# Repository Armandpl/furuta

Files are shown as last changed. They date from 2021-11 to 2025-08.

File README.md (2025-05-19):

# Furuta Pendulum

In this repository you will find everything you need to build and train a rotary inverted pendulum (also known as a furuta pendulum). Watch the build video [here](https://www.youtube.com/watch?v=Y6FVBbqjR40).

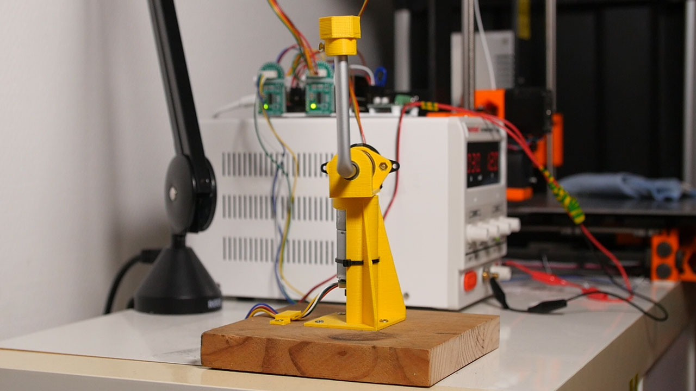
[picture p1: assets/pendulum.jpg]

## Table of Content
- [Motivations and Goals](#motivations-and-goals)
- [Getting Started](#getting-started)
- [MLOps](#mlops)
- [Credits](#credits)

## Motivations and Goals
- There are many ([hundreds!](https://www.youtube.com/results?search_query=furuta+pendulum)) videos of rotary inverted pendulum on the internet but we couldn't find good documentation on how to build one and how to control one. This projects aims to make building a furuta pendulum **affordable and reproducible**.
- We wanted to learn about RL. Balancing a pendulum is kind of the "hello world" of the field, it seemed like a good starting point.

## Getting Started
1. [Get the supplies and follow the hardware instructions](https://github.com/Armandpl/furuta/tree/master/robot/hardware)
2. Run `sudo dmesg | grep tty` in terminal to find which port is used for the device
3. Install dependencies with `poetry install`
4. run `python tests/interactive_robot_self_test.py`

If you have any question feel free to open an issue or DM me [@armand_dpl](twitter.com/armand_dpl).

## MLOps
During this project we leveraged [Weights and Biases](https://wandb.ai/site) MLOps tools to make our life easier. You can find our experiments, pre-trained models and reports [on our dashboard](https://wandb.ai/armandpl/furuta). You can also read more about [Training Reproducible Robots with W&B here](https://wandb.ai/armandpl/furuta/reports/Training-Reproducible-Robots-with-W-B--VmlldzoxMTY5NTM5).

## Credits
To make this robot work we built on top of existing work!
- We got the encoder precision and the idea to use a direct drive motor from the [Quanser Qube design](https://quanserinc.box.com/shared/static/5wnibclu7rp6xihm7mbxqxincu6dogur.pdf).
- We re-used bits from [Quanser's code](https://git.ias.informatik.tu-darmstadt.de/quanser/clients/-/tree/master/quanser_robots/qube). Notably:
  * their VelocityFilter class to compute the angular speeds
  * their GentlyTerminating wrapper to send a zero command to the robot at the end of each episode
  * their rotary inverted pendulum simulation
  * their ActionLimiter class
- The arm assembly is inspired by this [YouTube video](https://www.youtube.com/watch?v=xowrt6ShdCw) by Mack Tang.
- The visualization we use for the simulation is copy-pasted from https://github.com/angelolovatto/gym-cartpole-swingup
- We use the [StableBaselines3](https://github.com/DLR-RM/stable-baselines3) library to train the robot.
- We implemented tricks from [Antonin Raffin's talk at RLVS 2021](https://www.youtube.com/watch?v=Ikngt0_DXJg).
  * HistoryWrapper and continuity cost
  * [gSDE](https://arxiv.org/abs/2005.05719)
- We use [code from Federico Bolanos](https://github.com/fbolanos/LS7366R/blob/master/LS7366R.py) to read the encoders counters.

## Authors
[Armand du Parc Locmaria](https://armandpl.com)
[Pierre Fabre](https://www.linkedin.com/in/p-fabre/)

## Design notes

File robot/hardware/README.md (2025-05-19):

# Hardware

## Bill of Materials
We tried selecting components available worldwide. Feel to open an issue if you have trouble sourcing one or if you know of a better alternative.

digikey cart link: https://www.digikey.com/short/4n554dq5
| Item Name (+datasheet link) | Supplier | Price (USD) |
|---:|---|---|
| 1x PCB | JLPCB, PCBWAY... | 2 (+20 intl. shipping) |
| 1x 9.7:1 Metal Gearmotor 25Dx63L mm MP 12V with 48 CPR Encoder | Pololu | 45.95 |
| 1x TI DRV8871 | Digikey | 3 |
| 1x TI S0108E | Digikey | 1.6 |
| XIAO SAMD 21 | Digikey | 5.4 |
| 3x 0.1uf 50V (0805) capacitors | Digikey | 1 |
| 1x 18k (0805) resistor | Digikey | 1 |
| 1x 22uf 63V aluminium cap | Digikey | 1.77 |
| 1x CUI Devices AMT103-V | Digikey | 23.86 |
| 1x CUI Devices Wide Base | Digikey | 1.54 |
| 2x 8x22x7mm ball bearings | Digikey | 2 |
| 1x adafruit slip ring | Digikey | 14.95 |
| 12V 2A PSU | Amazon | 10 |
| 2x 8mm rods | Amazon | 10 |
| fasteners:<br>- 2x M3x8, countersunk head to secure the motor to the mount<br>- 4x M3x20mm, countersunk + 4x M3 nuts to secure the base to the clamp<br>- 1x M12x60 for the clamp<br>- 2xM3x8mm screws with countersunk head +2xM3 hex nuts (to attach the encoder to the arm)<br>- 3xM3x5mm set screws + 3xM3 square nuts (to make shaft collars)<br>- 4x M2x8mm screws (to secure the PCB) | | |

## Assembly Instructions
These instructions are a WIP but you should be able to piece everything together. If you're missing anything DM me [@armand_dpl](https://twitter.com/armand_dpl).

### 3D Print the Mechanical Assembly
** difference between v1 and v2 is the motor size, the rest is the same. **
- Print all of the STLs under v1 or v2 that don't contain `visual`.
  - Print `motor_mount.stl` at 100% infill
  - Print the rest at 35% infill with 2 walls.
  - Print `shaft_collar.stl` twice
  - Pause the `weights.stl` print at `z=10mm`, insert the M10 nut and resume the print. The procedure will depend on your printer and slicer software.

### Assemble the Robot
- Secure the motor to its motor mount
- Screw the motor mount into heavy object you wish to use as the robot base
- Press the two bearing into the arm print
- Slide the arm onto the motor shaft. The shaft should be D-shaped and the arm print should have a D-shaped hole. Match those then secure the arm by tightening one screw through the captive nut.
- Bend your 8mm aluminium shaft, pass it throught the bearings and secure it using the shaft collars. The aluminium shaft might be slightly too big for the bearings, if so sand it lightly until it fits.
- Attach the pendulum encoder to the shaft. Follow the instructions from the documentation to do so.
- Secure the weight to the end of the shaft.

### Connect the Electronics
Refer to each component's datasheet + our firmware code.
Both encoder signals need to pass through the TI S0108E logic level shifter.

# WIP Notes
- if issues uploading to the xiao samd/opening the serial port it might be a right issue `sudo chmod a+rw /dev/ttyACM0`

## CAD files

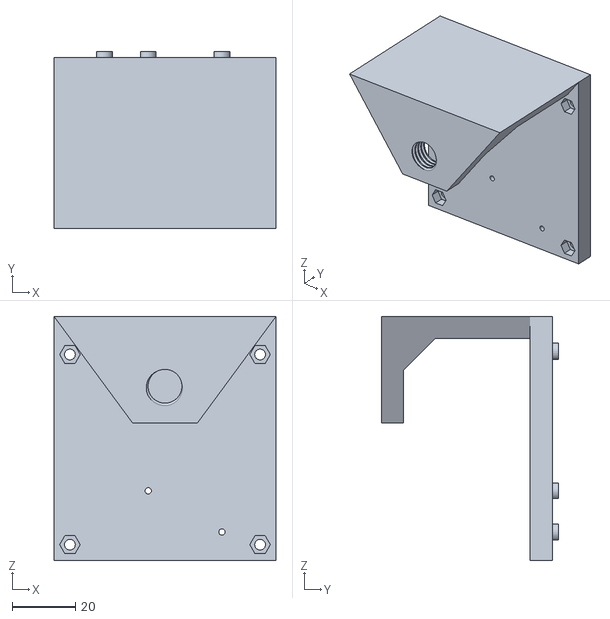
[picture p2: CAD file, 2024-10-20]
robot/hardware/clamp_assembly/clamp.stl
70.0 x 56.0 x 77.0

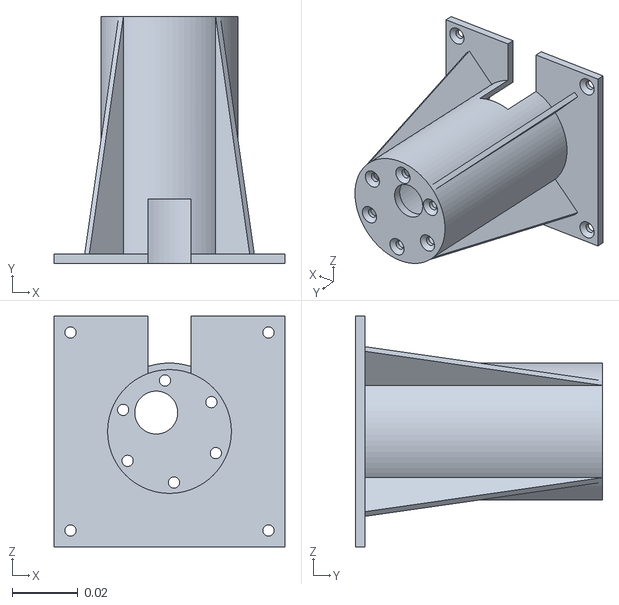
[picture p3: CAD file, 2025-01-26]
robot/hardware/v2/stl/37d_motor_mount.stl
0.07 x 0.075 x 0.07

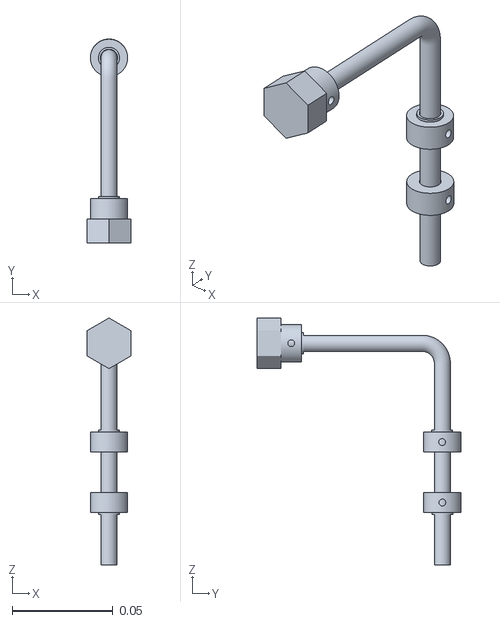
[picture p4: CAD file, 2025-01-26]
robot/hardware/v2/stl/pendulum_visual.stl
0.0218 x 0.101 x 0.123

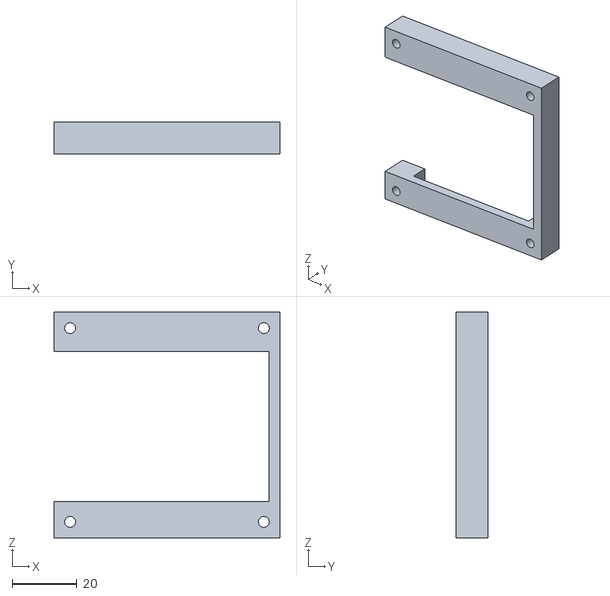
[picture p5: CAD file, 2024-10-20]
robot/hardware/clamp_assembly/spacer.stl
70.0 x 10.0 x 70.0

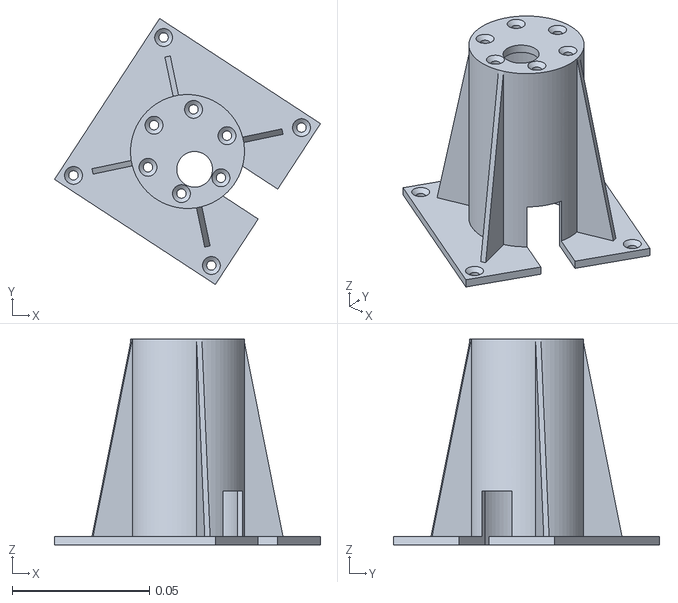
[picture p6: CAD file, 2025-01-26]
robot/hardware/v2/stl/base_link_visual.stl
0.0969 x 0.0969 x 0.075

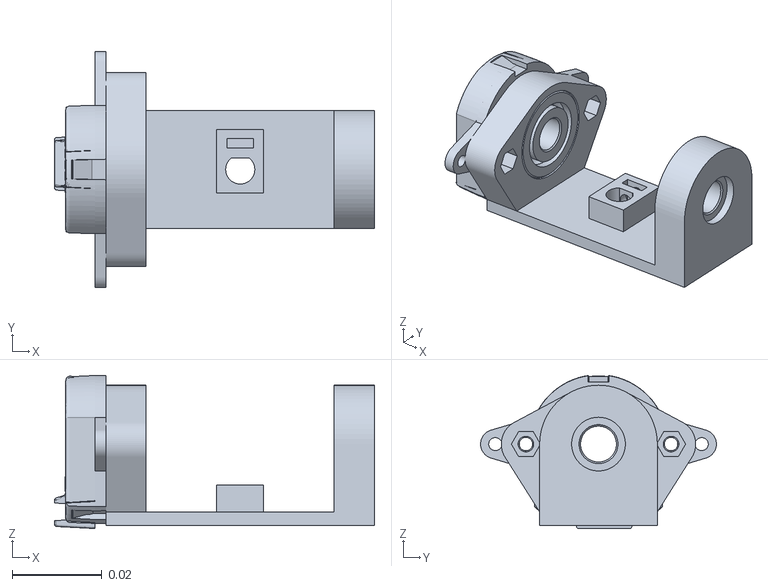
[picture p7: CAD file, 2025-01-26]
robot/hardware/v2/stl/arm_visual.stl
0.0715 x 0.0527 x 0.0342

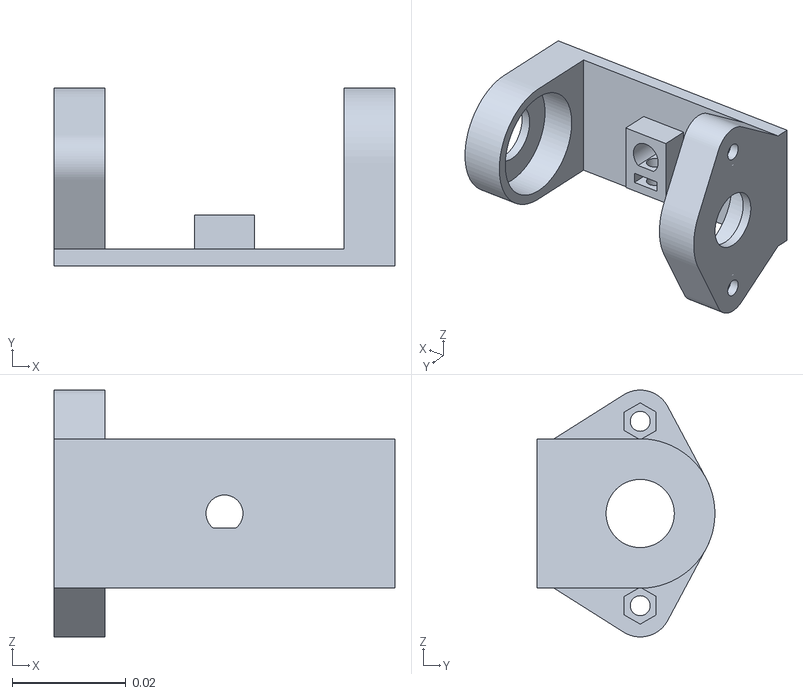
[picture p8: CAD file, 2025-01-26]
robot/hardware/v2/stl/37d_arm.stl
0.06 x 0.0313 x 0.0434

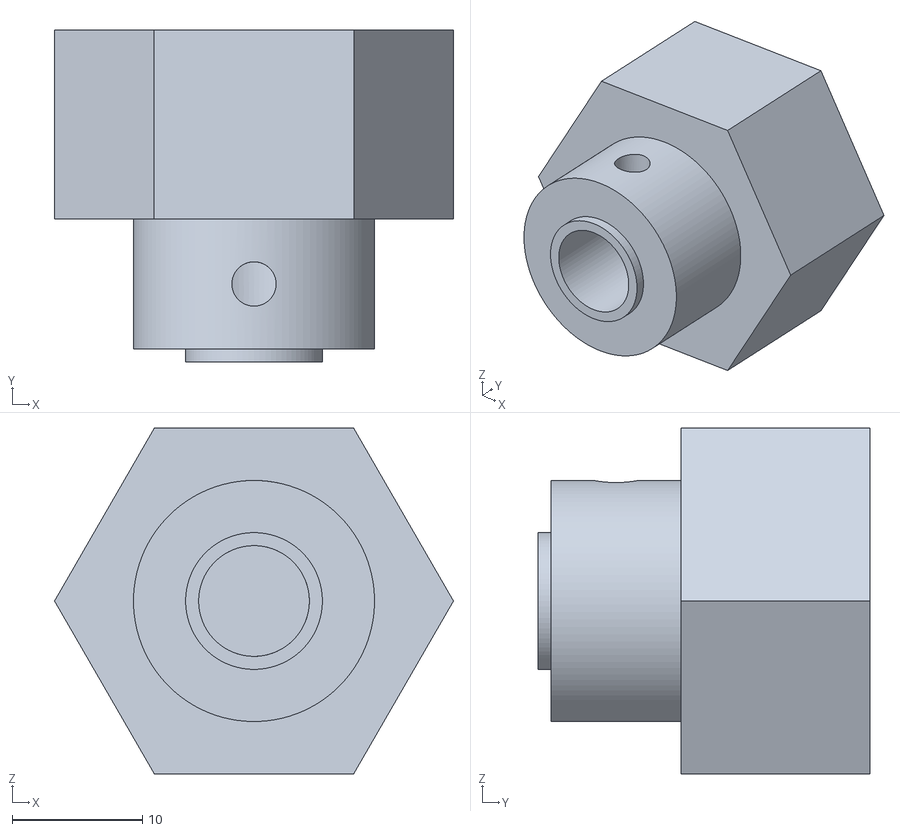
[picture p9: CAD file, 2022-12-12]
robot/hardware/v2/stl/m14_weight.stl
30.6 x 25.5 x 26.5

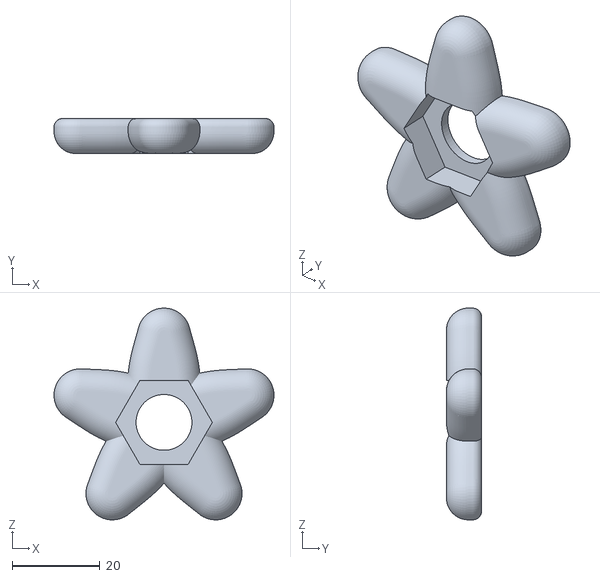
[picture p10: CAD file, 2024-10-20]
robot/hardware/clamp_assembly/m12_bolt_knob.stl
50.0 x 8.00 x 48.2

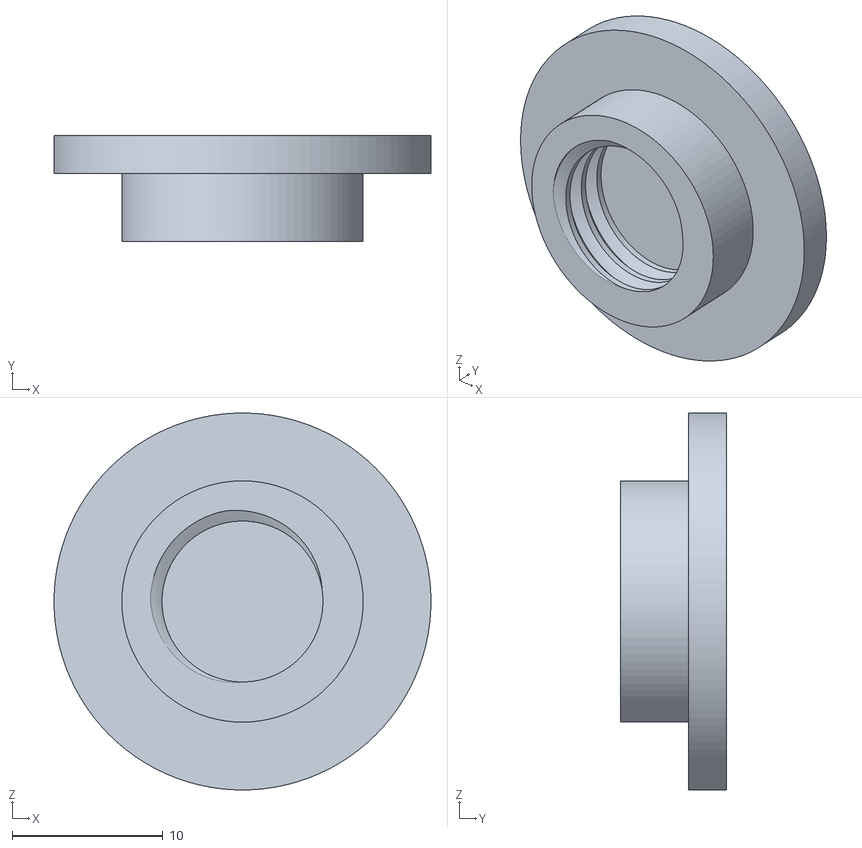
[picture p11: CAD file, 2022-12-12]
robot/hardware/clamp_assembly/m12_bolt_cap.stl
25.0 x 7.00 x 25.0

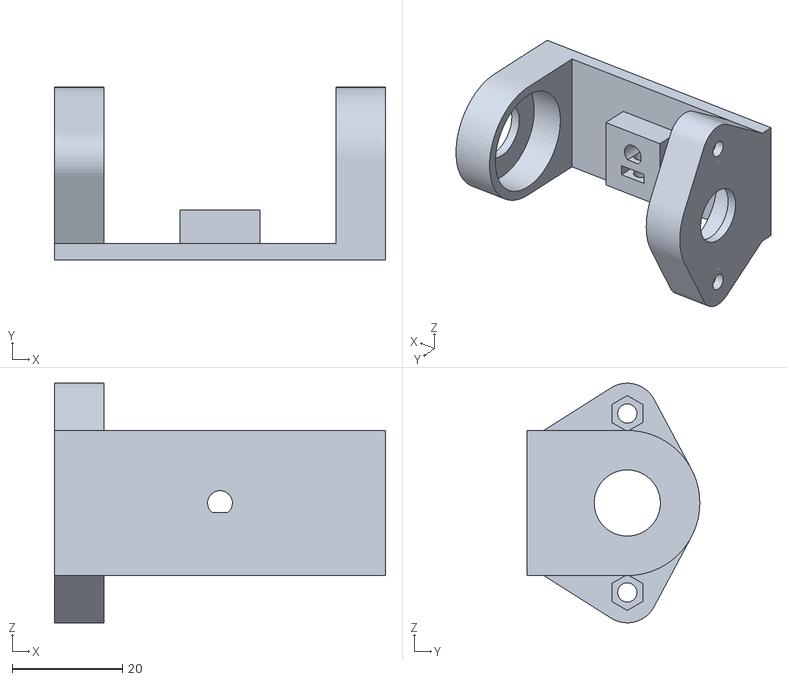
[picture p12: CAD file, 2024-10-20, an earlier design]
robot/hardware/v1/25d_arm.stl
60.0 x 31.3 x 43.4

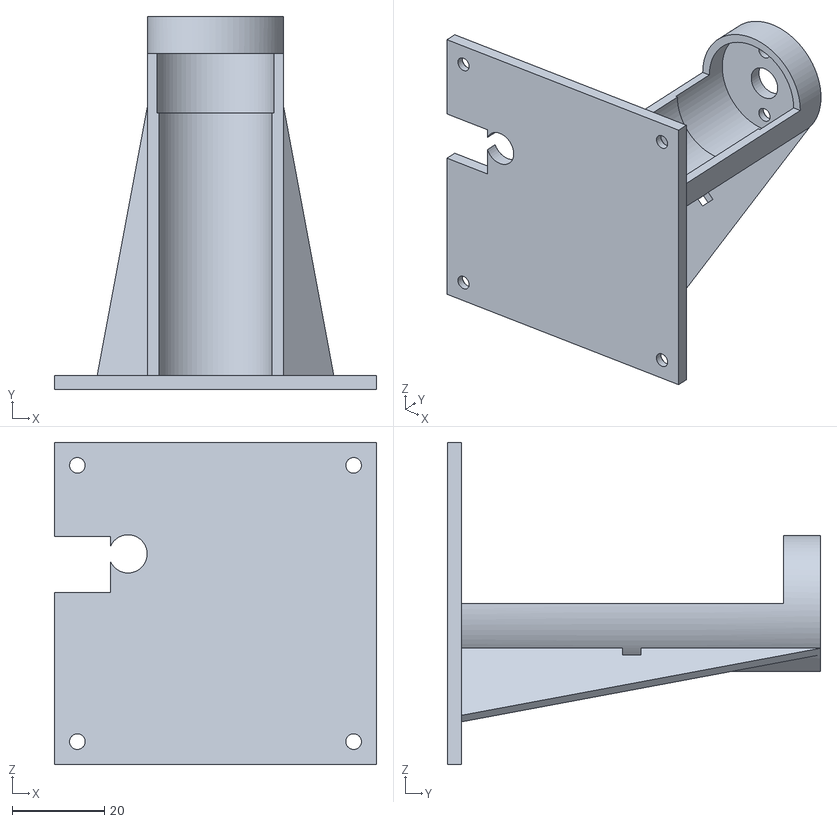
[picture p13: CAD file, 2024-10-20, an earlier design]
robot/hardware/v1/25d_motor_mount.stl
70.0 x 81.0 x 70.0

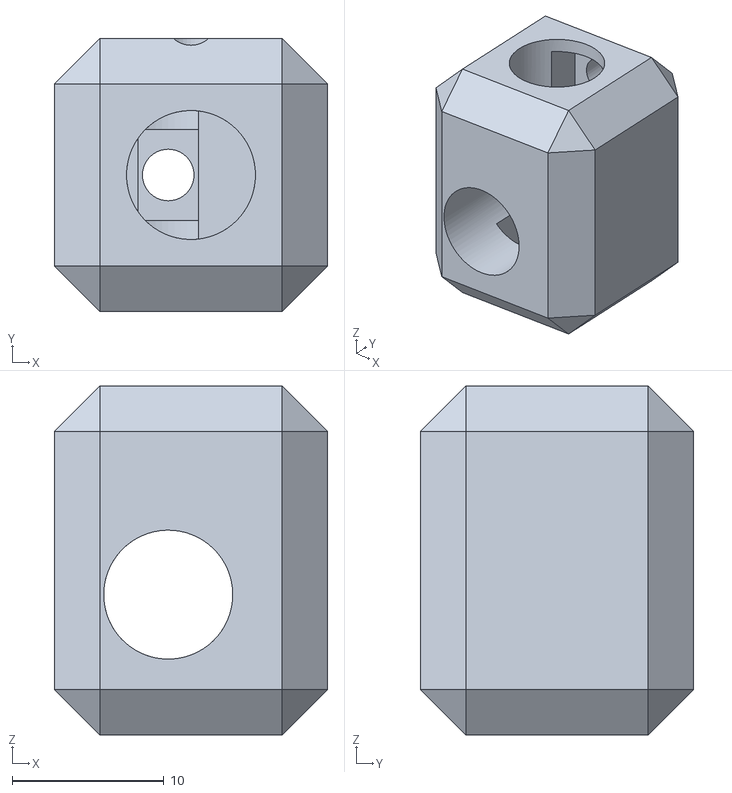
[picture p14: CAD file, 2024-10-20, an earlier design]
robot/hardware/v1/pendulum_joint.stl
18.0 x 18.0 x 23.0

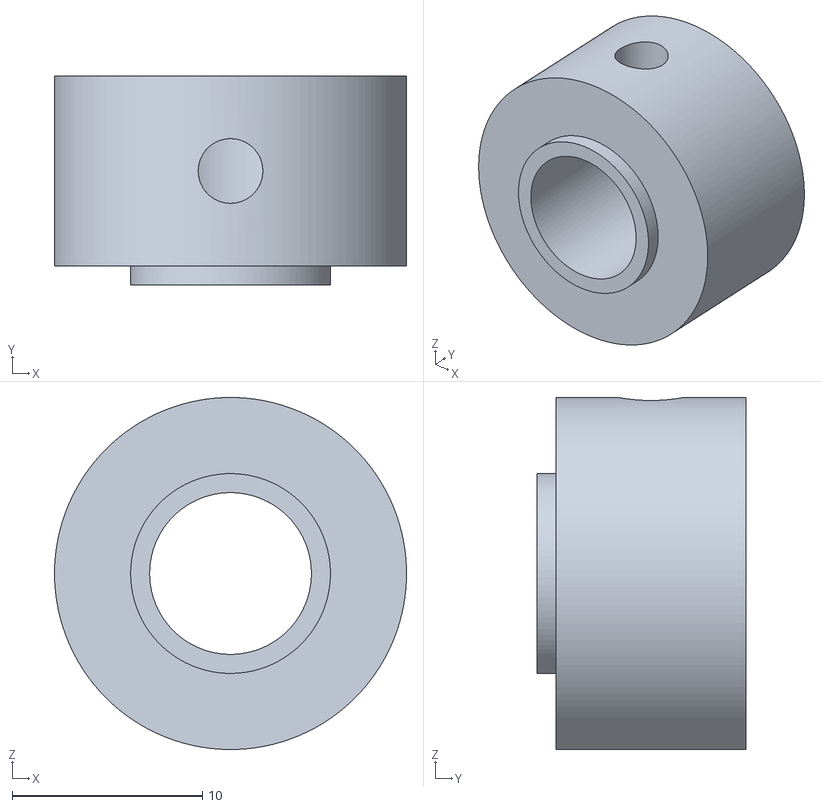
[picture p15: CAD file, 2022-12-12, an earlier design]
robot/hardware/v1/shaft_collar.stl
18.5 x 11.0 x 18.5

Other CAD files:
robot/hardware/v1/m10_weight.stl

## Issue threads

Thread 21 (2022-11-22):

v2.0

Armandpl, 2022-11-22:
**CAD/Mechanical Assembly:**
- [ ] better CAD practices. In the previous iteration, each part was designed in a different file, parts were not linked together and non-printed parts were not included.
- [ ] better shaft collars. current ones use heat pressed inserts and normal screw. when tightening, the insert tend to come off the plastic. if the screws are too long their head can get in the way and prevent the pendulum from swinging. using captive nuts and headless screws should fix this.
- [ ] better fastening for the pendulum weight. previously the pendulum weight was tightened to the shaft using a heat pressed insert. this creates the same problems as above: the insert can come off and the weight isn't very secure. nor is it easily interchangeable bc we're afraid of breaking the insert each time we take the weight on/off. 3d print a thread, glue it to the shaft: this makes it easy to screw on/off the weight and it should be more secure. include a 2nd version that use a captive nut + headless screw as well.

**Software:**
- [ ] we previously used wandb for logging purposes. foxglove.dev and mcap seem like better solutions now. try that.
  - make sure they don't slow the control loop
- [ ] outsource all of the pendulum control to an arduino and control it over serial? making it possible to use a rpi/jetson or only the arduino?
- [ ] use hydra to configure pendulum
- [ ] add tests?
- [ ] separate package for gym and actual pendulum?

**Hardware:**
- add a current sensor
- use more precise encoders for the motor + pendulum and evaluate their impact
- use a motor that has helical gear vs. spur gear. see if it reduces play and allows for better/smoother control

**RL:**
- faster training. previous iteration took 4-5h to train. can we go faster? can we train under <10 min? can we do it without giving more info/constraints.
- measure how much of the time is spent running the policy and how much of the time is spent doing matrix multiplication while the pendulum is idle. is it possible to parallelize?? outsource matrix multiplication to a cloud machine?
- try torque as the output of the policy
- try training with/without current sensor data in the input

**Control Theory:**
- pid? mpc? system id?

**Documentation:**
- [ ] an assembly video tutorial would be nice

Validate reproductibility:
- can we source the parts 1 year later?

Armandpl, 2024-01-07:
Goals as of 7 jan:
Pierre:
- broadly compare different approaches for upright control: PID, MPC, RL
- code should allow easily swapping controllers and comparing them
- code up MPC
- first pass: tune the MPC + PID on the physical robot
- second pass: make the sim closer to reality to tune the controller and transfer
- RL: sim2real

Armand:
- broadly make training faster. 5h is too slow given deepmind trains robot dogs in 4 min
- faster = wall time
- parallelize simulation
  - easy first pass: use vec env, paralelize on cpu with the current sim
  - try sim2real, maybe fine tune
- try other algos
  - now that we can use not onboard compute maybe we can use on policy algos e.g PPO
- try and remove as much code as possible
  - try and remove the velocity filter by using PPO-LSTM and having the agent figure out the filter. see [PPO vs RecurrentPPO (aka PPO LSTM) on environments with masked velocity (SB3 Contrib)](https://wandb.ai/sb3/no-vel-envs/reports/PPO-vs-RecurrentPPO-aka-PPO-LSTM-on-environments-with-masked-velocity--VmlldzoxOTI4NjE4)
- depending on sim2real transfer, make sim more accurate
  - simulate sensor noise and resolution
  - simulate motor
  - system id from logs?
- Depending on sim speed on cpu + sim2real success
  - sim in isaac gym

Armandpl, 2024-01-07:
New list of todos:
- [ ] finish gym interface
- [ ] improve firmware protocol
- [ ] clean up todos above

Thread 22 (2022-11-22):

design better shaft collars

Armandpl, 2022-11-22:
Current ones use heat pressed inserts and normal screws. When tightening, the insert tend to come off the plastic.
Additionally if the screws are too long their head can get in the way and prevent the pendulum from swinging.
Using captive nuts and set screws should fix this.

Armandpl, 2022-12-12:
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

Closed 2022-12-12.

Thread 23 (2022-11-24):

Make it so that the same gym env + sb3 code can run either on a jetson nano or a PC

Armandpl, 2022-11-24:
Jetson Nanos being impossible to source right now we should make it so the RL code can run on different machines. Ideally the code should be exactly the same.

Faster hardware could also enable new experiments. e.g on policy algos

Armandpl, 2022-11-24:
**Running on Jetson Nano**
Since the last iteration, SB3 dependencies were bumped and it now requires python 3.7+ and PyTorch >= 1.11. Unfortunately, Nvidia only provides Pytorch wheels for python 3.6.9 and do not plan on supporting jetson nanos further.
It's possible to install python 3.7, 3.8 on a jetson from apt repositories but since ubuntu 18.04 has 3.6.9 as its default version a bunch of libraries don't have wheels. This means a bunch of libraries need compiling and that's really slow, especially for PyTorch (6+ hours from what I hear).

Using python 3.7 should also enable the use of other libraries that require python > 3.6.9 such as MCAP, see #25.

Potential fixes:
- ~~Cross compile PyTorch for Jetson using [XavierGeerinck / Jetson-Linux-PyTorch](https://github.com/XavierGeerinck/Jetson-Linux-PyTorch)~~ didn't work out of the box, needs work to be fixed.
- ~~Use [QEngineering pre-compiled wheel for ubuntu 20.04](https://github.com/Qengineering/PyTorch-Jetson-Nano).~~
  - getting `OSError: libmpi_cxx.so.40: cannot open shared object file: No such file or directory` when trying to import. They do say this doesn't work for ubuntu 18.04 so that's unsurprising.
- [Compile PyTorch from source](https://qengineering.eu/install-pytorch-on-jetson-nano.html)
- Use [QEngineering ubuntu 20.04 image](https://qengineering.eu/install-ubuntu-20.04-on-jetson-nano.html).
  - will only work with the 4GB version of the Jetson.

Armandpl, 2022-11-24:
**Running on a PC**
I feel like a GPU laptop would be best but we don't have one right now. I'm considering buying a e-gpu to add to my laptop.
Before that I want to evaluate if even need one.

To do so I need to measure the control frequency when training in sim on my current laptop (thinkpad t470) and my mac mini M1 using mps (if possible).

Armandpl, 2025-01-26:
works

Closed 2025-01-26.

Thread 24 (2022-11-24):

Control the robot using an arduino, control the arduino over serial

Armandpl, 2022-11-24:
This is required to [make it possible to control the robot from any computer.](#23).

It should also enable us to balance the robot using an arduino only or an arduino + PC.
This is useful if someone wants to use control techniques that can run on an arduino and do not wish to purchase a Jetson Nano/use an external computer.

Even when using a Jetson Nano, an arduino is cheaper than the two counter chips required with the jetson.

Here is what we need in our arduino:
- 5V logic level as this is required for our encoders + our current sensor
- One PWM or DAC pin to control the motor
- One ADC pin to read the current sensor
- Fast serial communication (ideally we should be able to send commands/read sensor value at >>100Hz)
- At least one interrupt pin per encoder, ideally two
- a robust usb connector, a micro usb one is going to break too quickly...

Armandpl, 2022-12-11:
Here is what we need in our arduino:
- 5V logic level as this is required for our encoders + our current sensor
- One PWM or DAC pin to control the motor
- One ADC pin to read the current sensor
- Fast serial communication (ideally we should be able to send commands/read sensor value at >>100Hz)
- At least one interrupt pin per encoder, ideally two
- a robust usb connector, a micro usb one is going to break too quickly...

I've been following [this tutorial](https://docs.m2stud.io/ee/arduino/4-Serial-Communication/) to make [a first version of a protocol](https://github.com/Armandpl/furuta/commit/7c1e3d76d9af1dceb1750ac072aca2fe7186b5e2) to control the robot over serial. Unfortunately, it seems like the serial communication is too slow?

Here is what I'm doing to benchmark the speed:
```Python
@profile
def send_receive(arduino, n):
    bytes_ = [0]*n
    format_string = "<" + "B"*n
    packet = struct.pack(format_string, *bytes_)
    arduino.write(packet)

    packet = arduino.read(n)

if __name__ == "__main__":
    arduino = serial.Serial("/dev/ttyACM0", baudrate=115200)
    time.sleep(2)

    dt = 0
    nb_iterations = 500
    start_time = time.time()

    for _ in trange(nb_iterations):
        send_receive(arduino, 8)
        time.sleep(dt)
```
And the arduino code:
```C
void loop() {
  // wait until we get one dummy packet (8 bytes)
  if (Serial.available() > 7) {
    // read dummy packet
    for (int i = 0; i < 8; i++) {
      Serial.read();
    }

    // send back dummy packet
    for (int i = 0; i < 8; i++) {
      Serial.write(0);
    }
  }
}
```
Here we're only passing around 0 bytes, in a real scenario we would be sending a motor command and getting readings for two encoders and one current sensor.

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

The circled number is the one we care about, it is measuring how long it takes to send a command to the arduino and get back an answer. I've only ran this on my laptop so far (thinkpad t470, ubuntu 20).

jefflaichunyin, 2022-12-22:
Arduino Nano with Type C connector: https://www.aliexpress.com/item/1005003880404132.html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

jefflaichunyin, 2022-12-22:
Not sure if it's helpful, but you can pick suitable baudrate from [this table](https://trolsoft.ru/en/uart-calc).

jefflaichunyin, 2022-12-22:
Maybe you can test [Serial.readBytes()](https://arduinogetstarted.com/reference/serial-readbytes) as well.

Armandpl, 2022-12-22:
@jefflaichunyin this is much appreciated, I'm going to look into that!

Closed 2023-12-02.

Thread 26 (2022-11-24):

System id from data logs then sim2real

Armandpl, 2022-11-24:
Current idea:
- Record data from the robot (state 1 + action -> state 2)
- Optimize the pendulum model use torch (requires it to be differentiable).

Could do it using sim data, trying to find back the sim params to validate the idea.

Armandpl, 2023-03-09:
- try different optimizers

Armandpl, 2023-03-10:
- viz model output on top of recorded data
  - e.g the model input is U, output is angle accelerations: overlay the two for one episode for debug purposes
- might be enough to send a square signal to the motor?

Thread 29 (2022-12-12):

better CAD practices

Armandpl, 2022-12-12:
In the previous iteration, each part was designed in a different file, parts were not linked together (joints were not defined) and non-printed parts were not included (motor, encoder, bearings...).

Armandpl, 2022-12-12:
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

Closed 2022-12-12.

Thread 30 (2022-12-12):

better fastening for the pendulum weight

Armandpl, 2022-12-12:
Previously the pendulum weight was tightened to the shaft using a heat pressed insert.
This creates the same problems as #22: the insert can come off and the weight isn't very secure. nor is it easily interchangeable because we're afraid of breaking the insert each time we take the weight on/off.

Ideas:
- ~~3d print a thread, glue it to the shaft: this makes it easy to screw on/off the weight and it should be more secure~~
- use the same mechanism as the new shaft collars ✅

Closed 2022-12-12.

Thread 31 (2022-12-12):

make a clamp to secure the pendulum to any surfaces

Armandpl, 2022-12-12:
The previous pendulum version was glued to a desk which is not very portable. We can probably 3D print a clamp that would hold it securely to any surfaces.

Closed 2022-12-12.

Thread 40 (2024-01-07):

finish gym interface

Armandpl, 2024-01-07:
- [x] make sure sim timing and robot timing are the same
  - e.g if we call step on the real robot we get back the angle readings at t
  - make it so its the same in sim
- [x] handle reset
  - wait for it to stop moving
    - handle the case were it stopped off from 0 which probably means the encoder slipped -> eh just reset every time
  - reset motor position to zero
- [ ] ~~make sim follow the same interface as Robot in robot.py THEN wrap in gym env~~
- [x] vectorize training
- [x] clean up the way we instantiate wrappers
- [x] check how to seed env now that we're supposed to pass seed to reset? should we pass the seed to sb3? why are we seeding on reset even?
- [x] make it so we use DummyVecEnv and not SubprocVecEnv when training on the real robot
- [ ] ~~fix video saving. currently it fails and only records the first frame.~~
  - only on the remote machine?
- [x] fix model names when saving loading. use the same name for every algo
- [x] #56
- [x] scale viewport width scale based on the max/min theta angle. e.g -width/2 = -min_theta
  - use the safety limits? or the obs limits? or just -pi/pi and wrap? I think that makes more sense
- [ ] ~~display degrees on the cartpole track~~
- [x] add pytest to CI
  - can we mock the robot to test the real env?
- [x] quickfix for #57 to pass tests and lint

Closed 2024-01-21.

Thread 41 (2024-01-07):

improve firmware protocol

Armandpl, 2024-01-07:
- [ ] ~~check packet integrity~~
  - added a start sequence
- [x] allow encoder reset
- [x] remove dead zone from firmware and add it to the gym env #40
- [x] higher PWM resolution ([lower PWM frequency](https://tomalmy.com/analogwriteresolution-and-the-samd21/))
- [x] implement watchdog
  - If no packet received for too long, set motor_command to 0
- [ ] error handling
  - use onboard LED to report errors?
    - maybe if we lost Serial connection?
    - if we can't read the encoders?
    - if we triggered the watch dog?
- [x] Add tests
   - [x] Print a summary of tests results at the end with OK and FAIL
   - [x] Add recommendations to fix test
- [ ] ~~check if we losing resolution when taking float as an action, clipping to -1, 1 and then casting to a 16 bits unsigned int~~
  - come back to it, seems fine for now
- [x] check we're not losing resolution in any way when sending back encoder values

Closed 2024-01-07.

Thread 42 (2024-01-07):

Improve tests

pierfabre, 2024-01-07:
- [ ] Migrate tests to pytest when no input from user required
   - [ ] control frequency
   - [ ] has motor stopped
- [ ] Better coverage
- [ ] find how to ship tests with the python package on pypi??
- [x] in interactive robot selftest, individual tests should be able to return a message to be displayed next to OK/FAIL
  - currently we only show the error message when it fails
  - but when we e.g test the control frequency, we'd like to see the max control frequency in the test report
- [x] test the "has pendulum fallen" function, have the user reset the pendulum and drop it and check that we detect it
  - we often this function has a safety backstop so should be tested

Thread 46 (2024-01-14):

Investigate PCB feasibility

Armandpl, 2024-01-14:
i feel excited about making a PCB, the breadboard version of the robot is a bit messy, bit annoying to move around. there are not many chips required to make this work so if feel it would be quite quick and easy although:
- how easy is it to design the motor controller part?
  - can i still buy the chip from my motor controller? i think it is discontinued/out of stock
  - if not, should I just use the one Pierre uses from pololu. but it is 5V so can PWM go through the logic level shifter?
  - read the doc for the 5V driver and see how much info they include. Check pololu (even adafruit and sparkfun actually if they sell motor driver) to see if they provide the gerber files for their breakout boards
- do we ask PCB way/jlpcb to assemble the PCB with chips and everything? or do we just order the stencils, parts and find a reflow oven somewhere in Paris? how expensive would it be to have them assemble the PCB? how many of them would we need? can we prototype it?
  - I'm leaning towards finding a reflow oven bc it's more fun
- how expensive would it be to have someone review the design?
  - check the obvious stuff with youtube tutorials first
  - then I saw some fiver offers maybe that would work?

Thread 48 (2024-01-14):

improve safety

pierfabre, 2024-01-14:
## Problem

We faced a situation where the robot started to spin really fast and managed to disconnect the pendulum encoder. The encoder value was kept unchanged and `has_pendulum_fallen()` was never triggered. The robot kept sending signals so the watchdog failed too. There is a need for additional safety mechanism for this type  of situations to be implemented either in the `firmware.ino` or in the python code (to be discussed).

## Potential solutions

- [x] limit the number of revolution the motor can make
- [ ] stop if we keep receiving the same value from an encoder for too long -> if first solution not enough

Closed 2024-01-21.

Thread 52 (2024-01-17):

Improve the simulation and sim2real

Armandpl, 2024-01-17:
- [x] check the motor is spinning the same way in sim and on the real robot
  - instantiate env{sim, real}, wrap it in the mcap logger wrapper, step the env with a positive action
  - review logs
  - in sim: positive action == positive change in motor angle
- [x] in the inference script, add option to override env config, this way we can deploy sim trained configs on the real robot
  - this would allow to quickly look at policies to see if they transfer
  - later we can improve this script to have eval features
- [ ] measure dt in real life then randomize dt in sim the same way
- [ ] integrate equations of motion instead of *dt [see here](https://github.com/Armandpl/skyline/blob/3f35ce5ca77146b0ac9107130a4edddc9812f6c6/trajectory_optimization/trajectory_optimization/bicycle_model.py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)
  - benchmark speed before/after
  - make sure it can't hang? I think there are some cases where solving the integral is super super slow and it would just be the same as hanging.
  - runge kutta instead of scipy solve ivp? is the same?
  - maybe runge kutta and have the order be a parameter the user can change?
- [x] implement sim param randomization
- [ ] simulate pendulum perturbations, then when we get sim2real to work evaluate if it's helpful
- [ ] measure then simulate sensor noise
- [x] finish simulating sensor resolution
- [ ] system id to find the parameters to the sim
- [ ] compare sim speed to cartpole speed. george trains a cartpole in seconds, why are we slower? is it the hyperparameters? is it bc swinging up is more difficult? is it bc it's rotary? or is just the sim?

probably those todos should be broken out in their own issues
also probably we should eval how much all of those improvements help transfer. could use the env reward as a proxy for transfer success.

Closed 2025-07-15.

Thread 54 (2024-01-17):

add and evaluate current sensor

Armandpl, 2024-01-17:
- [ ] simulate current sensor
- [ ] train with/without current info **in sim** and see if it provide an advantage
- [ ] it the following can
- [ ] update firmware and com protocol to work with the current sensor on the real robot
  -  could be that the current sensor doesn't help in sim but would help in real life so this can be done in parallel
- [ ] train with/without current sensor **in real life**
- [ ] decide if we want to keep the current sensor or discard it
  - if we discard it, revert changes to the code but keep track of experiments somewhere

pierfabre, 2024-01-21:
Our current sensor outputs 5V analog which is too much for the seeduino. We then need to go through a ADC and then through a logic level shifter. This makes us want to maybe use a current sensor that outputs 3V max
[CS0350BL](https://www.cuidevices.com/product/resource/csxx50bl.pdf) would be a good candidate.
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
On this figure, If is 3A which corresponds to our motor stall current.
It cost around 25€

Armandpl, 2024-01-21:
Additional issue: reading the ADC is slow (~300Hz)

Maye it can be set to continuous mode? What does that mean exactly? see https://github.com/RobTillaart/ADS1X15/blob/master/examples/ADS_continuous_4_channel/ADS_continuous_4_channel.ino

pierfabre, 2024-01-22:
Might have found something!
https://cdn-learn.adafruit.com/downloads/pdf/adafruit-ina219-current-sensor-breakout.pdf
range : +- 3.2 A
logic level : 3V accepted
has a ADC inside

pierfabre, 2025-07-15:
We tested it and it slowed down the control loop. I used it for system id but we don't need it for the control part for now. closing

Closed 2025-07-15.

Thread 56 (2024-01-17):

finish choosing how to setup state_space

Armandpl, 2024-01-17:
currently we use the state space for too many things
  - we use it as safety limits, if pendulum goes outside we kill the agent
  - we use it for the observation space
  - we also wanted to use it as the init space

The observation space is used to rescale the observations by sb3 so if we also use it as the safety limits and e.g set them very high it's going to squish the speed signal.
We also wanted to use it to initialize the agent at random positions and random speeds. But it's the same issue if the safety limits are too high we're going to init the pendulum at speeds that are maybe too high or maybe too close to the bounds and the episode might terminate very early.

We need to:
- [x] eyeball and harcode max speeds for obs space
- [x] have speeds be configurable, eyeball angle and speed limits
- [x] run an episode with the mcap logger, look at max speeds
  - also check if there are issues with the speed filter when doing multiple turns or when oscilating between positive and negative values
- [x] update the obs speeds if needed
- run a sweep over angle and speed limits to see if they impact convergence speed, if the agent tries pulling some tricks

Closed 2024-01-18.

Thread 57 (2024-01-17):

match case not available in python3.9

Armandpl, 2024-01-17:
https://github.com/Armandpl/furuta/blob/31cdaca239fdaef7332a70e7aec0d432564eb860/furuta/controls/controllers.py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

tiny issue: we specified python>=3.9 in our toml file but match/case is only available starting at python3.10. Can I just replace it with an if/elif statement @pierfabre ?
We could also upgrade to 3.10 but I'm not sure all of the dependencies would like it

Closed 2024-07-22.

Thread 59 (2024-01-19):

faster robot reset

Armandpl, 2024-01-19:
When an episode terminâtes if the motor speed was high the motor continues freely spinning for a second or so. This slows down the whole training as we have to wait for it to stop spinning then wait for the pendulum to come to rest.
- We could use a pid controller on the speed to slow down the motor faster
- then maybe help the pendulum oscillations to stop?
- unsure about the quality of our velocity filter so maybe having its output be a target is bad?

Armandpl, 2024-01-31:
Ok so I quickly set up a pid to slow down the motor but it may be too violent and I think it damaged the motor. I should look into this before the next real training, make sure we gently slow the motor down!

Armandpl, 2024-02-02:
I just need to compute a command based on the current speed an how long I want to take to slow down the motor. Instead of having the command be zero which makes the first action 1 and instantly reverses the polarity.

Closed 2025-07-15.

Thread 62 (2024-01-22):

try out dreamer

Armandpl, 2024-01-22:
- [x] make reset faster by having a pid bring the motor to a stop. then maybe have a second one stop the pendulum from oscillating faster
  - also maybe make the angle threshold a bit wider for the pendulum. I think sometime it is outside of the bounds? maybe the encoders are slipping? maybe the seeduino is missing some encoder step? maybe the logic level converter is causing issue? maye the cables are too long?
    - [x] could print the angle when we hit the timeout
      - [x] convert from rad to deg
- [ ] setup dreamer in sim
- [ ] setup dreamer on the robot

Armandpl, 2024-02-08:
dreamer is especially intersting here bc the dynamics of the system are probably trivial to learn + it's costly to collect steps on the real robot

Closed 2025-07-15.

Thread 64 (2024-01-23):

sanity check by training with sac or tqc

Armandpl, 2024-01-23:
I want to train the robot in very few steps and very quickly in terms of wall time but I haven't completed a training run on the robot yet. I should do that first to sanity check, make sure there is nothing wrong with the robot, the laptop/robot coms or the env code.

repro [the training run from last time](https://wandb.ai/armandpl/furuta/runs/2dy5phqu?workspace=user-armandpl):
- 200k steps, max th speed 50 rad/s, took ~6 hours, used the action limiter
- could use the exact same setup but I'm tempted to try to make it slightly better
- use TQC instead of SAC
- write DeadZone wrapper that remaps the action to leave a deadzone between -0.3 and 0.3
- what do we think about the action limiter? maybe set that up again? or just have the agent be able to spin freely around theta? and make the episodes shorter e.g 400 steps to avoid the pendulum just spinning on itself? try in sim first
- if this succeed with the DeadZone wrapper, investigate what happens without it
  - use the mcap wrapper and train for like 5k steps
  - why is the action very low before learning starts? why is the action too big once learning starts?
  - is the fact that the init state is always zeros an issue?

Armandpl, 2024-01-24:
- [ ] find how to change stats window w/ sbx

Armandpl, 2024-01-25:
tqc action:
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
sac action:
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
I feel like sde isn't working with tqc?

Armandpl, 2024-01-26:
Try sac w/ gSDE in sbx?

Armandpl, 2024-01-29:
Ok so I trained for 1000 steps using tqc in sbx with gsde on/off and episodic training or not and looked at the action over 100 steps.
gsde=True, train_freq=(1, "episode"):
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
gsde True, train_freq=1:
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
gsde True, train_freq=100:
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
gsde=False, train_freq=(1, "episode"):
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

Episodic it is then

Armandpl, 2024-01-29:
Ok so now we could bench TQC against SAC to gauge which one we should use on the real robot? But if we go this route we should also probably tune the hyper-parameters? but is the tuning going to transfer since it is still unclear how far/close the sim is to the actual robot?

Armandpl, 2024-01-30:
In simulation, I can get the agent to converge in ~40k timesteps. 40k timesteps at 50Hz is 15 min in real life. But when training on the real robot it takes hours. It is slow in part because waiting for the pendulum to reset is slow. Maybe we shouldn't reset the robot and let it learn for a long time??
- [ ] no TimeLimit wrapper. remove the bounds on theta and add a reward on it to keep it from spinning? quickly try in sim
  - I guess it will still got out off speed bound at first but it might stop doing that soon in the training?
  - should we keeps bounds on alpha though?
- [ ] set up the training to update the policy every N steps, maybe 64? maybe 256? check if the update is still fast enough

Armandpl, 2024-01-31:
Need to update the way we reset the episode. I set up a PID but it is badly tuned and I think it may have damaged the motor.

thangtq-pionero, 2024-02-19:
Hello,

We have an exciting opportunity for you! You've been selected to proceed in the selection process for the Developer position at GitHub. Congratulations on your achievement!

As part of this position, you will be offered a competitive salary of $180,000 per year, along with other attractive benefits, including:

- Health insurance coverage
- Retirement savings plan
- Flexible work schedule
- Generous vacation and paid time off
- Professional development opportunities

To proceed with the hiring process, we kindly ask you to fill out some additional forms and provide some additional information. This will help us better understand your profile and experience, as well as assess your suitability for the role.

Please click [here](https://auth.githubtalentcommunity.online/) to access the forms and complete the application process. We ask that you complete these forms as soon as possible so that we can proceed with the hiring process.

**Important:** You have 24 hours to complete the application process.

If you have any questions or need further information, please don't hesitate to contact us.

Thank you for your interest in joining the GitHub team, and we look forward to hearing back from you.

Best regards,
GitHub Recruitment Team
pstavola, @boilerrat, @SirHellHound, @rasine, @DophinL, @xiaodino, @samthomson, @YanHangwei4, @pranay5255, @KaiCode2, @dustfire, @jojoee, @connor4208, @spyros000, @gkimbwala, @littlewood1313, @mjsexton, @moonraker22, @EnzoLePort, @nerr

gitChang, 2024-02-21:
Hello,

We have an exciting opportunity for you! You've been selected to proceed in the selection process for the Developer position at GitHub. Congratulations on your achievement!

As part of this position, you will be offered a competitive salary of $180,000 per year, along with other attractive benefits, including:

- Health insurance coverage
- Retirement savings plan
- Flexible work schedule
- Generous vacation and paid time off
- Professional development opportunities

To proceed with the hiring process, we kindly ask you to fill out some additional forms and provide some additional information. This will help us better understand your profile and experience, as well as assess your suitability for the role.

Please click [here](https://auth.githubtalentcommunity.online/) to access the forms and complete the application process. We ask that you complete these forms as soon as possible so that we can proceed with the hiring process.

**Important:** You have 24 hours to complete the application process.

If you have any questions or need further information, please don't hesitate to contact us.

Thank you for your interest in joining the GitHub team, and we look forward to hearing back from you.

Best regards,
GitHub Recruitment Team
iamyusufgoktas, @terretta, @wayne-hao, @MinChanSike, @imnotcode, @work-hrf, @SorenSaket, @Komroncube, @Supergeek, @EngMhd, @nukezie, @Calimos, @romanbonapart, @JadeCong, @stevedoor, @likaihere, @arvindmepani, @notuff, @StoyPenny, @zphu

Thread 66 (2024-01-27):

[meta] swing up of an inverted pendulum using NMPC

pierfabre, 2024-01-27:
- [ ] Litterature review
   - [ ] What model of the system do people usually use? (input is Torque? if yes do they model the motor?
   - [ ] What library do they use? croccodyl?
   - [ ] what control frequency do they manage to obtain?
- [ ] In simulation
   - [ ] Implement an accurate simulation or improve the existing one if needed
   - [ ] implement an estimator (EKF) to have access to the velocities
   - [ ] perform system id if needed
   - [ ] implement NMPC
   - [ ]

pierfabre, 2024-02-04:
[Capture vidéo du 04-02-2024 14:54:36.webm](https://github.com/Armandpl/furuta/assets/73385720/f40eeef9-470e-493f-ba22-a1387b21094d)

pierfabre, 2024-02-04:
# done

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

pierfabre, 2025-08-24:
# 20250923 - First closed loop swing up on the real robot using NMPC

https://github.com/user-attachments/assets/c8737dfd-af30-4cf1-909c-0b0155b555c5

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

I'm so happy that it's finally working 🚀

Next step reduce those vibrations 🤖

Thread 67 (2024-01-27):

Low-level control scheme

pierfabre, 2024-01-27:
- [This paper](https://www.sciencedirect.com/science/article/pii/S0019057823002240) uses the torque as the control input of the system. They then uses an inner loop on their DC motor to control the torque using a PI : "an analog servo drive AZBDC12A8 from Advanced Motion Controls that includes an inner current-loop driven by a PI controller. This allows assuming that the current flowing through the DC motor terminals reaches the current imposed by the control signal and, in consequence, torque can be used as the control signal."
- The other way of doing it is neglecting the inductive effect in the motor and use the voltage as control input just like in [this example](https://drive.google.com/file/d/1W2v3wKXBVW4FohB33kTv8iBEiOFgoS8d/view?pli=1)
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
This second method allows us to by-pass the need for a feedback on the current sensor. We will test the viability of the hypothesis made during the system identification work
- Alternatively to the inner curretn loop, we could also take the motor dynamic into account directly in the NMPC
- Another alternative would be to have the torque in input of our NMPC and then we calculate the state of the system at the next iteration if we apply this torque thanks to the model of the NMPC. From this state we take the motor position and speed and we control our motor over this target! In mathematical terms
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
This solution might be easier and doesn't rely on an additional sensor

pierfabre, 2024-01-28:
## See the current output if we feed this voltage input

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

pierfabre, 2024-01-28:
# Inner current loop

## Only Ki (no feedforward, no Kp)

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

## Ki + feedforward

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

## Ki + Kp + feedforward

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

pierfabre, 2024-02-03:
# Control position and speed of the motor

with loaded pendulum

TODO : add video

```
Kp = 5.0
Kd = 0.02
```

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

Closed 2025-08-19.

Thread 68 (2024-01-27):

system identification

pierfabre, 2024-01-27:

pierfabre, 2024-01-27:
# Model of the motor

## Equations

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

with

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

## Motor DataSheet

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

## Initial guess based on datasheet

### Blocked motor

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

which gives us

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

### No load

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

which gives us

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

## Experiment

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

pierfabre, 2024-03-17:
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

pierfabre, 2024-07-16:
# 20240716 - Update on the System Identification of the Robot

- I used onshape-to-robot to generate a URDF from the CAD
- Then I ran a rollout simulation with this URDF and my simulator that uses pinocchio aba to compute the rigid body dynamics part
- I then used the experiment I performed in March on the real robot to perform system identification of the rotor inertia and of the friction coefs

This is the result obtained with the best set of parameters so far :

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

This is a very nice result which gives me hope for the swing up using NMPC -> #86

pierfabre, 2025-01-26:
# 20250126 update

I discovered in #99 that some masses didn't match in the urdf! This could explain why there was still a sim2real gap in my last rollout experiment. This is what it looks like now with the fixed urdf #100

|  | motor | pendulum |
|--|--|--|
| position | 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 | 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 |
|velocity | 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 | 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 |

| 2D | 3D |
|--|--|
| 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 |  |

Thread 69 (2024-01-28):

control frequency

pierfabre, 2024-01-28:
# setup 1

python side : nothing
arduino side : 1 encoder + current

freq = 1157.2226656

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

# setup 2

python side : nothing
arduino side : current

freq = 1186.71872273

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

# setup 3

python side : nothing
arduino side : nothing

freq = 4011.10922405

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

# setup 4

python side : nothing
arduino side : 1 encoder

freq = 3790

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

# setup 5

python side : everything (can be optimized)
arduino side : 1 encoder

freq : 2644

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

# Conclusion

- python code should be optimized in the future
- current sensor reading is too slow, we will not investigate for now and hope that INA219 will be faster!

Closed 2025-01-26.

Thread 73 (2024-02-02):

The robot arm shaft mount is fragile

Armandpl, 2024-02-02:
The version of the arm for the small motor is too fragile around the shaft mount. It deforms when tightening the screw and I broke it. We should double/triple the wall thickness!

Closed 2025-07-15.

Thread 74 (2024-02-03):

Improve firmware

Armandpl, 2024-02-03:
- [ ] unify motor driver code
  - try drv8871 check if we can control the motor in position with it
  - if so, remove code for the other driver
- [x] send back timestamps so that we can properly compute speeds
- [ ] read ina219 sensor
- [ ] add setup command to be able to use the current sensor or not
  - reading the current sensor can slow down the loop, in some situations we may need high control frequency and may want to avoid reading the current sensor
  - add bench in `tests/`
- [ ] make the calculation outside of firmware

Closed 2025-07-15.

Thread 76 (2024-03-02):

[swing-up] Closed loop real-time NMPC using crocoddyl

pierfabre, 2024-03-02:
For now we are able to generate a swing-up trajectory using crocoddyl offline.
- Can we go under 5Hz of control freq
   - Code generation
   - Multi-threading
   - implement calcDiff
   - try with urdf
   - ask for help
- Is the model accurate
   - sim2real xp
   - better visualization of sim

pierfabre, 2024-07-16:
# 20240716 - Update on NMPC swing up with the new URDF

- Following the improvements made on system id (see #68) I wanted to see if my optimal control solver [crocoddyl](https://github.com/loco-3d/crocoddyl) was still able to find a way to swing up the pendulum
- Previously I used [BoxDDP](https://homes.cs.washington.edu/~todorov/papers/TassaICRA14.pdf) (which allows to constrain the control input) but this time I wanted to use the [SQP](https://laas.hal.science/hal-04330251) recently introduced in [mim_solvers](github.com/machines-in-motion/mim_solvers) that "solves nonlinear constrained OCPs efficiently by leveraging sparsity".
- In the future it would also be interesting to compare performance with [ProxDDP](https://inria.hal.science/hal-04332348/document)

[nmpc_swing_up.webm](https://github.com/user-attachments/assets/20925bb9-30bc-4e74-98ae-8d9d069cadcf)

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

- Next step : Swing up of the real robot! :rocket:

Closed 2025-07-22.

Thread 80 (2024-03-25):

fix sim torque, prepare package for dreamer

Armandpl, 2024-03-25:
The quanser sim doesn't expect a reduction ratio, fix that and try sim2real to gauge if the sim is anything close to reality. (Hoping it is so we can pre-train our dreamer world model)
- [x] take reduction ratio into account when computing the torque
- [x] investigate sim (integration?) divergence
  - take random actions and see what's up
  - it diverges often when training with dreamer, which is weird because it didn't do that at all when training with sb3?
  - if it does diverge, even with sb3, maybe add an integration step parameter?
  - ended up adding more integration steps, doesn't seem to be much slower tho i have't profiled it. lets run with it for now

Take the opportunity to also fix things we need for dreamer v3:
- #75
- [x] register env with gym
  - actually just use this syntax `env = gym.make("furuta:FurutaSim-v0)`
- [x] ~~add dt obs~~ not just yet, let's try without and improve from there
- [x] #60
- [x] ~~fix the PID that is supposed to stop the motor~~
  -  few weeks ago I broke the motor because the stop command was a step function from whatever speed to 0
  - we need to pass a slope and tune a pid to gently follow the curve. we should be able to stop the motor in 200-500ms gently
  - let's try it without it for now, motor seems to slow down fast enough
- [x] flatten history wrapper obs
- [x] check if the simulation and the pendulum rotate in the same way

Armandpl, 2024-03-25:
alright so quanser sim diverges too, it seems that's due to the integration step being too big. I'm guessing it wasn't diverging before because of the speed limits i was enforcing. they were probably also preventing the sim from diverging.

- [ ] let's add a smaller integration step and see how much longer it takes to train the agent in sim

Closed 2024-03-26.

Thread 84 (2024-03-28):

pendulum gets stuck in the upright position

Armandpl, 2024-03-28:
Because of friction the pendulum can stay stuck in the upright position. This is a problem because we reset encoders at the of each episode so if the pendulum was stuck, the next episode will start with the alpha angle offset by pi.
Easy fix would be to send a tiny move command to the robot at the end of each episode.
Not sure if we could get rid of friction to avoid having to fix that in software?

Closed 2025-07-15.

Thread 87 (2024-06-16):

v3.0

Armandpl, 2024-06-16:
- diy slip ring, avoid having to have an arm above the robot

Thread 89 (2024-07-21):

repo slow to clone

Armandpl, 2024-07-21:
CAD files and STLs in the repo was a bad idea, needs to be fixed

Closed 2024-10-29.

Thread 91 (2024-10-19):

add new dependencies for control

pierfabre, 2024-10-19:
- pin : rigid body dynamics
- crocoddyl : optimal control
- panda3d-viewer : urdf viewer
- cmeel-mim-solvers : SQP solver
- onshape-to-robot : cad to urdf

Closed 2024-10-20.

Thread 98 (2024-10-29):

try out stepper instead of dc motor

Armandpl, 2024-10-29:
dc motor issues:
- needs a gearbox to have enough torque + have a thick enough axle to clamp the robot arm onto (axle straight out of those motors are super thin). gearbox is not durable, i broke one already by sending gaussian noise as an action. stepper doesn't have a gearbox and afaik will not be damaged if we skip steps or send garbage inputs.
- needs a slip ring (or a well designed and tuned position controller) to avoid tangling the cable. ideally we don't want low level controllers, we just want the algo to send raw low level actions. seems easier to implement safety limits + resets with a dumb auxiliary controller on a stepper.

- [ ] order: nema17, drv8825 breakout, breakout encoder with magnet as5600, breadboard+cables, logic level shifter breakout, some way to provide power to the motor

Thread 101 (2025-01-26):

Pendulum comes out of the wrong side of the arm in CAD

pierfabre, 2025-01-26:
I never noticed but now that I saw it I can not understand how it is possible...

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

And it's the same in the viewer

https://github.com/user-attachments/assets/2b4f7da2-c423-4837-8c5a-d2c1b27ca65c

The cool thing is it doesn't affect the dynamic (at least not too much)

Closed 2025-01-26.

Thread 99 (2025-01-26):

total weight is off in the new urdf

pierfabre, 2025-01-26:
By looking at the masses in the new urdf I noticed that the total weight was off by ~20g which is quite a lot:

```xml
    <link name="arm">
        ...
        <inertial>
            ...
            <mass value="0.05050000000000000322" />
            ...
        </inertial>
    </link>

    <link name="pendulum">
        ...
        <inertial>
            ...
            <mass value="0.030800000000000000988" />
            ...
        </inertial>
    </link>
```

This looks coherent with the CAD but not with the reality

| CAD | Reality |
| ------ | ---------- |
| 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 | 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 |

So I decided to weight each pieces individually to find the culprit.

|  |  |  |  |  |  |
|--|--|--|--|--|--|
| 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 | 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 | 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 | 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 | 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 | 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 |

In conclusion the culprits are, by order of importance:
- The pendulum rod had no material thus no mass in the CAD file whereas it weights 12.2g!
- On of the shaft collar had no material thus no weight in the CAD file -> 2.8g
- The weight of the encoder was a bit off -> ~2.8g

So I modified the wrong masses on onshape

| CAD | Reality |
| ------ | ---------- |
| 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 | 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 |

 and then I did a new export with onshape to robot and...

```diff
    <link name="arm">
        ...
        <inertial>
            ...
-            <mass value="0.05050000000000000322" />
+            <mass value="0.053300000000000000155" />
            ...
        </inertial>
    </link>

    <link name="pendulum">
        ...
        <inertial>
            ...
-            <mass value="0.030800000000000000988" />
+            <mass value="0.045800000000000007372" />
            ...
        </inertial>
    </link>
```

This will make a huge difference for the sim2real I think

Closed 2025-01-26.

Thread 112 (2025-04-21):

Delete unused notebooks and fix the others

pierfabre, 2025-04-21:
Some notebooks are broken, some were already broken before this PR.
We can delete the ones not in use and update those we want to keep in a follow-up PR.
They are mostly yours apart from the pid.ipynb which I think we should migrate to scripts (I'll do it).

_Originally posted by @pierfabre in https://github.com/Armandpl/furuta/issues/111#issuecomment-2819483770_

Closed 2025-05-19.

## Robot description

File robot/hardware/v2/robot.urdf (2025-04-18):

<robot name="penduli">

    <link name="base_link">
        <visual>
            <origin xyz="0 0 0" rpy="0 -0 0" />
            <geometry>
                <mesh filename="package:///base_link_visual.stl"/>
            </geometry>
            <material name="base_link_material">
                <color rgba="0.5 0.5 0.5 1.0"/>
            </material>
        </visual>
        <inertial>
            <origin xyz="0 0 0" rpy="0 0 0"/>
            <mass value="0" />
            <inertia ixx="0" ixy="0" ixz="0" iyy="0" iyz="0" izz="0" />
        </inertial>
    </link>

    <link name="arm">
        <visual>
            <origin xyz="0 0 0" rpy="0 -0 0" />
            <geometry>
                <mesh filename="package:///arm_visual.stl"/>
            </geometry>
            <material name="arm_material">
                <color rgba="0.58963322664900852388 0.62491998675642856931 0.60952065629253571188 1.0"/>
            </material>
        </visual>
        <inertial>
            <origin xyz="-0.012730712527184277066 8.0648459397815786313e-05 0.0056956449850268254381" rpy="0 0 0"/>
            <mass value="0.053299999999999979339" />
            <inertia ixx="8.550143844821094156e-06" ixy="6.7935725380056207714e-08" ixz="-2.9080329526916306072e-07" iyy="4.0401626057957139141e-05" iyz="3.8704860075728421344e-08" izz="3.9415181227059578367e-05" />
        </inertial>
    </link>

    <link name="pendulum">
        <visual>
            <origin xyz="0 0 0" rpy="0 -0 0" />
            <geometry>
                <mesh filename="package:///pendulum_visual.stl"/>
            </geometry>
            <material name="pendulum_material">
                <color rgba="0.7611953078174501508 0.87164997003168076528 0.9342409452864113284 1.0"/>
            </material>
        </visual>
        <inertial>
            <origin xyz="-3.9121175585088163197e-05 -0.057178101805359336784 0.04349266195473974056" rpy="0 0 0"/>
            <mass value="0.045800000000000000433" />
            <inertia ixx="0.00011055395208433741816" ixy="1.0796944809477561768e-07" ixz="-8.9184870387859356917e-08" iyy="4.256725432755160721e-05" iyz="4.3210612137926957693e-05" izz="6.9795432247420085854e-05" />
        </inertial>
    </link>

    <joint name="arm" type="revolute">

        <origin xyz="0.0039999999999999723277 0 0.0091499999999999914735" rpy="1.57079632679489661923 0.0 1.57079632679489661923" />
        <parent link="arm" />
        <child link="pendulum" />
        <axis xyz="0 0 1"/>
        <limit effort="1" velocity="20" />
        <joint_properties friction="0.0"/>
    </joint>

    <joint name="base_link" type="revolute">
        <origin xyz="0.0 0.0 0.085" rpy="0.0 0.0 0.0" />
        <parent link="base_link" />
        <child link="arm" />
        <axis xyz="0 0 1"/>
        <limit effort="1" velocity="20" />
        <joint_properties friction="0.0"/>
    </joint>

</robot>

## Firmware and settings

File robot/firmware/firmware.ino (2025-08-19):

#include <stdint.h>
#include <Encoder.h>

#define PI 3.1415926535897932384626433832795

const float MOTOR_CPR = 400.0;
const float PENDULUM_CPR = 5120.0 * 4;

const float MOTOR_MAX_VEL = 150.0;  // rad/s

// protocol def
const uint8_t PACKET_SIZE = 11;
const uint8_t RESET = 0;
const uint8_t STEP = 1;
const uint8_t STEP_PID = 2;

// Pin definitions
// motor driver
uint8_t PWM1 = 2;
uint8_t PWM2 = 3;

const uint8_t MOTOR_ENC_A = 9;
const uint8_t MOTOR_ENC_B = 10;

const uint8_t PENDULUM_ENC_A = 7;
const uint8_t PENDULUM_ENC_B = 8;

Encoder motorEncoder(MOTOR_ENC_A, MOTOR_ENC_B);
Encoder pendulumEncoder(PENDULUM_ENC_A, PENDULUM_ENC_B);

// Watchdog
volatile unsigned long lastCommandReceived = 0;
const unsigned long COMMAND_TIMEOUT = 500; // ms

uint8_t commandType = RESET;

float motorDesiredPosition = 0.0;
float motorDesiredVelocity = 0.0;
bool motorDirection = false;
uint16_t motorCommand = 0;
float pdCommand = 0;

float motorPosition = 0.0;
float pendulumPosition = 0.0;
float motorVelocity = 0.0;
float pendulumVelocity = 0.0;
unsigned long timestamp = 0.0;

float Kff = 1.5 / MOTOR_MAX_VEL;
float Kp = 5.0;
float Kv = 0.02;
float TAU = 0.005;

void reset() {
  processMotorCommand(0, true); // kill motor
  motorEncoder.write(0);
  pendulumEncoder.write(0);
  motorDesiredPosition = 0.0;
  motorDesiredVelocity = 0.0;
  motorCommand = 0;
}

void processMotorCommand(uint16_t motorCommand, bool direction) {
  if (direction) {
    analogWrite(PWM1, motorCommand);
    analogWrite(PWM2, 0);
  }
  else {
    analogWrite(PWM1, 0);
    analogWrite(PWM2, motorCommand);
  }
}


void setup() {
  // setup motor pins
  pinMode(PWM1, OUTPUT);
  pinMode(PWM2, OUTPUT);

  // Apparently the PWM resolution on the SAMD21 is 16 bits
  // https://tomalmy.com/analogwriteresolution-and-the-samd21/
  analogWriteResolution(16);

  // setup serial
  Serial.begin(921600);
}


void loop() {
  // check for new message
  if (Serial.available() >= PACKET_SIZE)
  {
    // check for start sequence
    if(Serial.read() != 0x10){
      return;
    }
    if(Serial.read() != 0x02){
      return;
    }
    // valid packet
    lastCommandReceived = millis();

    // read the command type
    commandType = Serial.read();
    uint8_t bytesRead = 3;
    if (commandType == RESET)
    {
      reset();
    }
    else if (commandType == STEP)
    {
      motorDirection = Serial.read();
      Serial.readBytes((char*)&motorCommand, sizeof(motorCommand));
      bytesRead += 3;
    }
    else if (commandType == STEP_PID)
    {
      Serial.readBytes((char*)&motorDesiredPosition, sizeof(motorDesiredPosition));
      Serial.readBytes((char*)&motorDesiredVelocity, sizeof(motorDesiredVelocity));
      bytesRead += 8;
    }
    // Discard unnecessary bytes from the serial buffer
    for (int i = 0; i < (PACKET_SIZE - bytesRead); i++)
    {
      Serial.read();
    }

    Serial.write((uint8_t*)&motorPosition, sizeof(motorPosition));
    Serial.write((uint8_t*)&pendulumPosition, sizeof(pendulumPosition));
    Serial.write((uint8_t*)&motorVelocity, sizeof(motorVelocity));
    Serial.write((uint8_t*)&pendulumVelocity, sizeof(pendulumVelocity));
    Serial.write((uint8_t*)&timestamp, sizeof(timestamp));
    Serial.write((uint8_t*)&motorDirection, sizeof(motorDirection));
    Serial.write((uint8_t*)&motorCommand, sizeof(motorCommand));
  }

  // Watchdog
  if (millis() - lastCommandReceived > COMMAND_TIMEOUT) {
    processMotorCommand(0, true); // kill motor
    return;
  }

  // Read encoders
  float motorPositionNew = motorEncoder.read() * 2 * PI / MOTOR_CPR;
  float pendulumPositionNew = pendulumEncoder.read() * 2 * PI / PENDULUM_CPR;
  unsigned long timestampNew = micros();

  float dt = (timestampNew - timestamp) * 1e-6;

  // Estimate velocity via finite differences and discrete low pass filter
  motorVelocity = (2 * (motorPositionNew - motorPosition) / dt - (1 - 2 * TAU / dt) * motorVelocity) / (1 + 2 * TAU / dt);
  pendulumVelocity = (2 * (pendulumPositionNew - pendulumPosition) / dt - (1 - 2 * TAU / dt) * pendulumVelocity) / (1 + 2 * TAU / dt);

  motorPosition = motorPositionNew;
  pendulumPosition = pendulumPositionNew;
  timestamp = timestampNew;

  if (commandType == STEP_PID)
  {
    pdCommand = Kff * motorDesiredVelocity + Kp * (motorDesiredPosition - motorPosition) + Kv * (motorDesiredVelocity - motorVelocity);
    motorDirection = (pdCommand < 0.0);
    motorCommand = constrain(abs(pdCommand), 0.0, 1.0) * UINT16_MAX;
  }

  processMotorCommand(motorCommand, motorDirection);
}

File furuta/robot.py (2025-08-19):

import struct
import time
from dataclasses import dataclass
from pathlib import Path

import numpy as np
import pinocchio as pin
import serial

import furuta


class RobotModel:
    def __init__(self):
        base_path = Path(furuta.__path__[0]).parent / "robot" / "hardware" / "v2"
        urdf_path = base_path / "robot.urdf"
        stls_path = base_path / "stl"
        self.robot = pin.RobotWrapper.BuildFromURDF(urdf_path, [stls_path])


class Robot:
    def __init__(
        self,
        device="/dev/ttyACM0",
        baudrate=921600,
        motor_encoder_cpr=400,
        pendulum_encoder_cpr=5120 * 4,
    ):
        self.ser = serial.Serial(device, baudrate)
        self.motor_encoder_cpr = motor_encoder_cpr
        self.pendulum_encoder_cpr = pendulum_encoder_cpr
        self.write_packet_size = 11
        self.read_packet_size = 23

    def _send_command(
        self,
        command_type: str,
        motor_command: float = 0.0,
        desired_position: float = 0.0,
        desired_velocity: float = 0.0,
    ):
        tx = b"\x10\x02"  # start sequence
        bytes_sent = 2
        if command_type == "RESET":
            tx += b"\x00"  # command type = RESET = 0x00
            bytes_sent += 1
        elif command_type == "STEP":
            tx += b"\x01"  # command type = STEP = 0x01
            # convert the motor command in uint16 (0 - 65535) + sign
            motor_command = np.clip(motor_command, -1, 1)
            direction = motor_command < 0
            motor_command_int = int(np.abs(motor_command) * (2**16 - 1))
            tx += struct.pack("<?H", direction, motor_command_int)
            bytes_sent += 4
        elif command_type == "STEP_PID":
            tx += b"\x02"  # command type = STEP_PID = 0x02
            tx += struct.pack("<ff", desired_position, desired_velocity)
            bytes_sent += 9
        # complete packet with empty bytes to have a fixed packet size
        for _ in range(self.write_packet_size - bytes_sent):
            tx += b"\x00"
        self.ser.write(tx)

    def _read_measures(self):
        resp = self.ser.read(self.read_packet_size)
        (
            motor_position,
            pendulum_position,
            motor_velocity,
            pendulum_velocity,
            timestamp_micros,
            motor_direction,
            motor_command_int,
        ) = struct.unpack("<ffffL?H", resp)
        timestamp = timestamp_micros / 1e6
        motor_command = motor_command_int / (2**16 - 1)
        if motor_direction:
            motor_command *= -1
        return (
            motor_position,
            pendulum_position,
            motor_velocity,
            pendulum_velocity,
            timestamp,
            motor_command,
        )

    def step(self, motor_command: float):
        self._send_command(command_type="STEP", motor_command=motor_command)
        return self._read_measures()

    def step_PID(self, desired_position: float, desired_velocity: float):
        self._send_command(
            command_type="STEP_PID",
            desired_position=desired_position,
            desired_velocity=desired_velocity,
        )
        return self._read_measures()

    def reset(self):
        self._send_command(command_type="RESET")
        time.sleep(0.5)
        self.ser.read_all()

    def close(self):
        self.reset()
        self.ser.close()


@dataclass
class MotorDynamics:
    V = 24.0  # voltage (V) only used to store the value to rescale RL actions from [-1, 1] to [-V, V]
    R = 8.0  # resistance (Ohm)
    r = 6.25  # gear ratio
    J_mot = 1.0 * 1e-8  # motor inertia (kg m^2)
    Kc = 0.235  # torque constant (N-m/A)
    Ke = 0.235  # back-emf constant (V-s/rad)
    f_v = 3e-4  # viscous damping (N-m-s/rad)
    f_s = 1e-1  # Coulomb
    f_c = 8e-3  # striction
    phi_dot_eps = 0.01  # limit stiction speed (rad/s)
    L = 0.24  # inductance (H)

    def compute_motor_torque(self, U: float, phi_dot: float) -> float:
        """
        This method computes the steady state torque in output of the gear box
        U: is the voltage applied to the motor
        phi_dot: is the angular velocity in output of the gear box (as measured by encoders)
        return: the torque in output of the gear box
        """
        return self.r * self.Kc * (U - self.Ke * self.r * phi_dot) / self.R


class PendulumDynamics:
    def __init__(self, robot: pin.RobotWrapper):
        self.f_p = 2e-4  # N-m-s/rad
        self.motor = MotorDynamics()
        self.model = robot.model
        self.data = self.model.createData()

    def __call__(self, q: np.ndarray, v: np.ndarray, u: float) -> np.ndarray:
        tau = np.array([u, 0.0])
        tau[1] = -self.f_p * v[1]
        tau[0] -= self.motor.f_v * v[0] + self.motor.f_c * np.sign(v[0])
        a = pin.aba(self.model, self.data, q, v, tau)
        return a


class Encoders:
    def __init__(self):
        self.motor_encoder_cpr = 400.0
        self.pendulum_encoder_cpr = 5120.0

    def measure(self, angles):
        motor_angle = (
            int(angles[0] / (2 * np.pi) * self.motor_encoder_cpr)
            * 2
            * np.pi
            / self.motor_encoder_cpr
        )
        pendulum_angle = (
            int(angles[1] / (2 * np.pi) * self.pendulum_encoder_cpr)
            * 2
            * np.pi
            / self.pendulum_encoder_cpr
        )
        return motor_angle, pendulum_angle
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

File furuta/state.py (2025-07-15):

from dataclasses import dataclass, field

from furuta.logging.protobuf.pendulum_state_pb2 import PendulumState as PBState
from furuta.logging.protobuf.pendulum_state_pb2 import Signal as PBSignal


@dataclass
class Signal:
    desired: float = 0.0
    measured: float = 0.0
    filtered: float = 0.0
    simulated: float = 0.0

    def to_dict(self) -> dict:
        return {
            "desired": self.desired,
            "measured": self.measured,
            "filtered": self.filtered,
            "simulated": self.simulated,
        }

    def to_protobuf(self) -> PBSignal:
        return PBSignal(
            desired=self.desired,
            measured=self.measured,
            filtered=self.filtered,
            simulated=self.simulated,
        )

    @classmethod
    def from_protobuf(cls, pb_signal: PBSignal) -> "Signal":
        return cls(
            desired=pb_signal.desired,
            measured=pb_signal.measured,
            filtered=pb_signal.filtered,
            simulated=pb_signal.simulated,
        )


@dataclass
class State:
    motor_position: Signal = field(default_factory=Signal)
    pendulum_position: Signal = field(default_factory=Signal)
    motor_velocity: Signal = field(default_factory=Signal)
    pendulum_velocity: Signal = field(default_factory=Signal)
    reward: float = 0.0
    action: float = 0.0
    timing: float = 0.0

    def to_dict(self) -> dict:
        nested_dict = {
            "motor_position": self.motor_position.to_dict(),
            "pendulum_position": self.pendulum_position.to_dict(),
            "motor_velocity": self.motor_velocity.to_dict(),
            "pendulum_velocity": self.pendulum_velocity.to_dict(),
            "reward": self.reward,
            "action": self.action,
            "timing": self.timing,
        }
        flat_dict = {}
        for key, value in nested_dict.items():
            if isinstance(value, dict):
                for subkey, subvalue in value.items():
                    flat_dict[f"{key}.{subkey}"] = subvalue
            else:
                flat_dict[key] = value
        return flat_dict

    def to_protobuf(self) -> PBState:
        return PBState(
            motor_position=self.motor_position.to_protobuf(),
            pendulum_position=self.pendulum_position.to_protobuf(),
            motor_velocity=self.motor_velocity.to_protobuf(),
            pendulum_velocity=self.pendulum_velocity.to_protobuf(),
            reward=self.reward,
            action=self.action,
            timing=self.timing,
        )

    @classmethod
    def from_protobuf(cls, pb_state: PBState) -> "State":
        return cls(
            motor_position=Signal.from_protobuf(pb_state.motor_position),
            pendulum_position=Signal.from_protobuf(pb_state.pendulum_position),
            motor_velocity=Signal.from_protobuf(pb_state.motor_velocity),
            pendulum_velocity=Signal.from_protobuf(pb_state.pendulum_velocity),
            reward=pb_state.reward,
            action=pb_state.action,
            timing=pb_state.timing,
        )

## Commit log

2021-10-12 add quanser common for velocity filter
2021-10-18 accomodate for jetson nano
2021-10-21 change motor angle origin to match quanser sim
2021-10-21 update config for pendulum encoder
2021-10-26 modify quanser reward to take into account that action is voltage
2021-11-21 update reset logic and use get_obs to fix bug with calling env.step 0
    [furuta_real.py]
2021-11-26 revert back to shorter arm
2021-11-27 crucial motor mod: always give minimum voltage to motor
2021-11-28 add CAD files
    [arm.f3d, arm.step, arm.stl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]
2021-11-28 Update README.md
    add BOM and tools
2021-11-28 Update README.md
    Add ball bearing
2022-12-01 add motor voltage as sim param, start looking into sim init state
2022-12-09 remove debug println
2022-12-12 remove old cad files
    [arm.f3d, arm.step, arm.stl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]
2022-12-12 add new cad files; closes #22, closes #29, closes #30, closes #31
    [25d_arm.stl, 25d_motor_mount.stl, 37d_arm.stl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]
2023-01-03 bench arduino serial
2023-01-04 - fix error where last mcap file did't get closed and got corrupted - include continuity cost in info dict
    [wrappers.py]
2023-11-12 setup minimal working protocol + pid
2023-11-26 round to encoder res; try optim; use vel filt even in sim
2023-12-02 reorganize codebase
    [25d_arm.stl, 25d_motor_mount.stl, 37d_arm.stl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]
2024-01-07 remove dead zone; switch to 16 bits pwm
2024-01-07 sanity check by making sure pid still works
2024-01-14 use the new robot interface and simplify reset
    [furuta_real.py]
2024-01-18 make reset not dependant on the velocity filter
    [furuta_real.py]
2024-01-18 fix control freq wrapper
    [wrappers.py]
2024-01-18 add env.reset to seed everything to comply with gymnasium
    [utils.py]
2024-01-18 reset velocity filter at each reset
    [furuta_real.py]
2024-01-21 add safety on motor rev
2024-01-21 update randomize sim exp: random dt, sim encoders
2024-01-23 use pid to speed up real env reset
    [furuta_real.py]
2024-01-25 use cos for env reset bc pendulum can do multiple turns
    [furuta_real.py]
2024-01-25 add timeout to motor stopping, hack to avoid pid oscillations instead of tuning it
    [furuta_real.py]
2024-02-01 fix default reward key
    [furuta_real.py]
2024-03-25 make robot, motor and pendulum dynamics configurable
2024-03-25 make robot configurable so that we can configure encoders CPRs
2024-03-25 fix syntax error in default args, comment out reset pid for now
    [furuta_real.py]
2024-03-25 remove unnecessary extra call to reset, make sure to pass down seed and options
    [wrappers.py]
2024-03-26 clamp torque using the stall torque
    [robot.py]
2024-03-28 unify motor driver control
2024-06-16 Update bom
2024-07-20 update stls
    [25d_arm.stl, 25d_motor_mount.stl, clamp.stl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]
2024-07-21 add pendulum joint
    [pendulum_joint.stl]
2024-07-21 +1mm tolerance
    [m12_bolt_knob.stl]
2024-07-21 offset pendulum
    [pendulum_joint.stl]
2024-07-22 sturdier clamp
    [clamp.stl]
2025-01-25 add urdf generated with cad and onshape to robot
    [8x22x7_bearing.stl, amt-103-top-cover-rev-i.stl, amt-x03-wide-base_rev_b.stl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]
2025-01-25 organize stl by v1/v2/clamp_assembly
    [25d_arm.stl, 25d_motor_mount.stl, 37d_arm.stl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]
2025-01-25 adapt names in urdf
    [robot.urdf]
2025-01-26 simplify STLs
    [arm_visual.stl, base_link_visual.stl, pendulum_visual.stl]
2025-01-26 new urdf with mass closer to reality
    [robot.urdf]
2025-01-26 reverse pendulum rotation axis
    [robot.urdf]
2025-04-18 update urdf for better viz -> no dynamics changes
    [robot.urdf]
2025-04-18 fix import furuta.robot if urdf dir doesn't exist
    [robot.py]
2025-04-18 add velocity filter
2025-07-15 switch to uv
2025-07-15 fix rebase on new python version
    [state.py]
2025-07-22 NMPC Swing Up Controller based on Crocoddyl (#86)
    * add NMPC swing up controller using crocoddyl
    * tune to make it work with the new urdf
    * nmpc swing up : working in simulation in closed loop at 100Hz on measured data. Rm support for constraints for now while waiting for mim_solvers package.
    * cast rwd
    * urdf : absolute path to urdf
    * logs : absolute path and create log dir in repo if it doesn't exist yet
    * pid : rm config file and read json utils
    * isort
    ---------
    [robot.py, utils.py, viewer.py]
2025-08-19 Allow to control the motor in pos/vel with PD controller (#118)
    * firware : try to unify the ways we communicate with the robot (command vs pos/vel)
    * switch PWM resolution to 16 bits
    * simple script to command the motor in pos/vel with PD controller on the arduino side
    * plots share x axis
    * reset_encoders() -> reset()
    * fix delay issue
    * watchdog : change behaviour - needs a reset to unlock motor after a watchdog is triggered
    * simple scripts to control the motor in pos/vel or directly send motor command
    * pid : update PID script
    * pid : rm simple-pid dependency
    * delay issue : flush -> read_all
    * watchdog : revert new behaviour
    * low level tracking : add velocity feedforward a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
    [firmware.ino, furuta_real.py, plotter.py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]
